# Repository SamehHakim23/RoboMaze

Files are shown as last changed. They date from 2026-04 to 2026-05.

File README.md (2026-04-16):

# RoboMaze — Autonomous Maze-Solving Robot

**ECNG 4504 — Embedded Systems for Wireless Communications**  
AUC Spring 2026 | Team 2

---

## Team Members

| Name | Student ID | Email |
|---|---|---|
| Sameh Ahmed | 900211681 | samehahmedhakim@aucegypt.edu |
| Hamza El Meadawy | 900211560 | hamzaelmeadwy@aucegypt.edu |
| Mariam Moataz | 900213249 | mariammoataz@aucegypt.edu |
| Menna AbdelHamed | 900212035 | mennnaa12@aucegypt.edu |

---

## Project Overview

RoboMaze is a fully autonomous maze-solving robot built on the ESP32 microcontroller. It uses a 5-sensor infrared array to follow black lines and navigate a maze autonomously across four sequential runs with no human intervention after the initial start command:

1. **LHR (Run 1)** — Explores the maze using the Left-Hand Rule, recording all junctions and decisions
2. **Back (Run 2)** — Returns to start along a simplified reverse path
3. **Run 2 (Run 3)** — Re-navigates the maze on the shortest discovered path using Manhattan distance heuristic
4. **Back 2 (Run 4)** — Returns to start along the optimized path

A live web application visualizes the maze map in real time and allows full wireless control via WiFi or Bluetooth BLE.

---

## Repository Structure

RoboMaze/
├── Firmware/           # ESP32 C++ source code (PlatformIO + Arduino)
├── Hardware(KiCad)/    # KiCad hardware schematic
├── Webapp/             # React + TypeScript web application
└── Docs/               # Architecture diagrams, contribution docs, team details

---

## Hardware

| Component | Model | Role |
|---|---|---|
| Microcontroller | ESP32 DevKit V1 | Main compute, WiFi 802.11, BLE 4.2 |
| IR Sensors | TCRT5000 × 5 | Line detection array |
| Motor Driver | L298N | Dual H-bridge PWM motor control |
| DC Motors | 25GA370 130RPM × 2 | Differential drive |
| Wheel Encoders | Hall-effect × 2 | Corridor distance measurement |

---

## Firmware

**Platform:** PlatformIO + Arduino Framework  
**Language:** C++  

Key features:
- Left-Hand Rule maze exploration with junction recording
- Triplet path simplification algorithm
- Run 2 Manhattan distance navigation with axis-priority selection
- WebSocket server on port 81 with full JSON telemetry protocol
- BLE GATT server with TX notify and RX write characteristics
- Encoder-based corridor distance measurement with auto-calibration

```ini
lib_deps =
    links2004/WebSockets@^2.4.0
    bblanchon/ArduinoJson@^6.21.0
board_build.partitions = huge_app.csv
```

---

## Web Application

**Stack:** React + TypeScript + Vite (frontend), Express (backend)  
**URL:** robomaze.net

Features:
- Live maze map with proportional corridor rendering
- Real-time sensor display and robot state indicator
- Full robot control panel (start, back, run2, back2, pause, e-stop)
- WiFi mode: direct browser → `ws://172.20.10.9:81`
- BLE mode: Web Bluetooth API (Chrome desktop)

---

## Wireless Communication

| Channel | Details |
|---|---|
| WiFi | Static IP 172.20.10.9 · WebSocket port 81 |
| BLE | Device: RoboMaze · Service UUID: 12345678-1234-1234-1234-123456789abc |
| Telnet | Port 23 · Raw log streaming |

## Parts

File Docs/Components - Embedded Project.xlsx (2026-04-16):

Hardware
Category | Component | Recommended Example | Purpose | Notes / Why Needed
MCU (Brain) | Microcontroller Board | ESP32 DevKit V1 | Runs all code, reads sensors, controls motors | Best choice because BLE is built-in for Phase 1
Sensors | IR Line Sensor Array | 5-channel QTR / IR array (TCRT5000) | Detects black line + intersections | 5 sensors makes intersection detection reliable
Motors | DC Gear Motors (x4) | 25ga370 | Movement of robot | Gear motors provide torque + stability
Motor Driver | Dual H-Bridge Driver | TB6612FNG | Drives motors with PWM + direction control | More efficient and modern than L298N
Chassis | Robot Car Frame | Acrylic / 4-wheel chassis | Holds all components | Must fit within 40×40 cm limit
Wheels | Robot Wheels (x4) | 65mm wheels | Movement traction | Match motor shaft type
Power
Category | Component | Recommended Example | Purpose | Notes
Battery | Li-ion / LiPo Battery Pack (x2) | 3.7v batteries | Powers motors + MCU | Strong enough for motors, stable voltage
Voltage Regulator | Buck Converter | LM2596 step-down | Converts battery → 5V/3.3V | ESP32 requires stable 5V input
Power Switch | Toggle switch | Any | On/off control | Required for safety
Wiring | Jumper wires + connectors | Male/Female Dupont | Connections during Phase 0 | Phase 2 replaces with PCB traces
Communication
Category | Component | Example | Purpose | Notes
USB Cable | USB-C / Micro USB | Depends on ESP32 board | Upload code + serial debugging | Required always
Optional BLE Module | Not needed | ESP32 has BLE built in | Wireless Phase 1 | Already included
Extra
Category | Component | Example | Purpose | Notes
Encoder (Optional Bonus) | Wheel encoder | Optical encoder | Measures speed accurately | Helps advanced PID + bonus sophistication
Breadboard (Temporary) | Mini breadboard | Any | Quick prototyping | Useful before soldering
Screws + Spacers | Mounting kit | M3 kit | Fix components on chassis | Makes build professional
3D Printed Parts | Custom mounts | PLA prints | Clean design | Bonus marks possible
Software
Software Category | Tool | Purpose | Why Needed | Notes
IDE / Coding | VS Code + PlatformIO | Write + upload ESP32 firmware | Best professional workflow for ESP32
Version Control | GitHub Repository | Required submission + teamwork | Doctor requires repo with MCU code + docs
Hardware Design | KiCAD | Wiring schematics + Phase 2 PCB | Hand drawing is not accepted
Serial Monitor | PlatformIO Serial Monitor | Debug sensor + motor values | Essential for tuning PID

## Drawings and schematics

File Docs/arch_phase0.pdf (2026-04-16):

# ROBOMAZE — SOFTWARE ARCH ITECTURE

## Phase 0 · Autonomous Maze Solver (LHR + Path Replay)

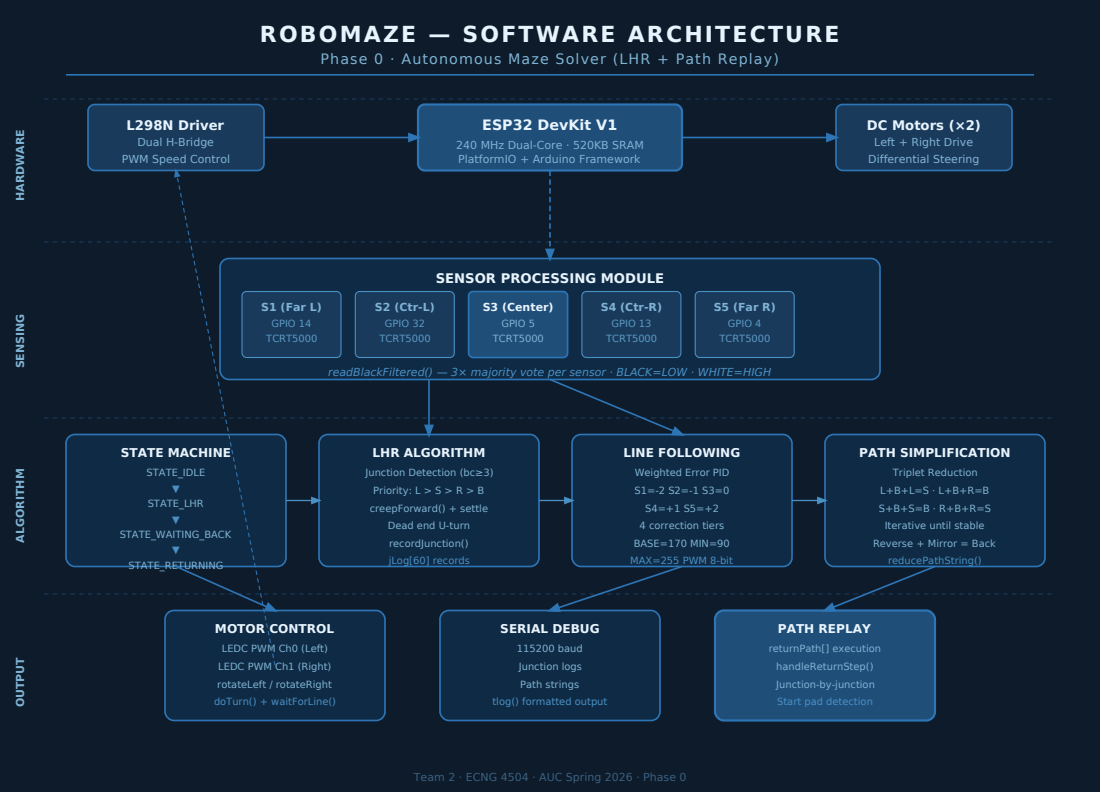
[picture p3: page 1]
S1 (Far L) GPIO 14 TCRT5000; S2 (Ctr-L) GPIO 32 TCRT5000; S3 (Center) GPIO 5 TCRT5000; S4 (Ctr-R) GPIO 13 TCRT5000; S5 (Far R) GPIO 4 TCRT5000; STATE MACHINE; STATE_IDLE ▼ STATE_LHR ▼ STATE_WAITING_BACK ▼ STATE_RETURNING

L298N Driver
Dual H-Bridge
PWM Speed Control

ESP32 DevKit V1
240 MHz Dual-Core · 520KB SRAM
PlatformIO + Arduino Framework

DC Motors (×2)
Left + Right Drive
Differential Steering

HARDWARE SENSING ALGORITHM OUTPUT

SENSOR PROCESSING MODULE

readBlackFiltered() — 3× majority vote per sensor · BLACK=LOW · WHITE=HIGH

LHR ALGORITHM
Junction Detection (bc≥3)
Priority: L > S > R > B
creepForward() + settle
Dead end U-turn
recordJunction()
jLog[60] records

LINE FOLLOWING
Weighted Error PID
4 correction tiers
BASE=170 MIN=90
MAX=255 PWM 8-bit

PATH SIMPLIFICATION
Triplet Reduction
Iterative until stable
Reverse + Mirror = Back
reducePathString()

MOTOR CONTROL
LEDC PWM Ch0 (Left)
LEDC PWM Ch1 (Right)
rotateLeft / rotateRight
doTurn() + waitForLine()

SERIAL DEBUG
115200 baud
Junction logs
Path strings
tlog() formatted output

PATH REPLAY
returnPath[] execution
handleReturnStep()
Junction-by-junction
Start pad detection

Team 2 · ECNG 4504 · AUC Spring 2026 · Phase 0

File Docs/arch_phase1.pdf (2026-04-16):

# ROBOMAZE — SOFTWARE ARCH ITECTURE

## Phase 1 · Full System with Wireless Communication

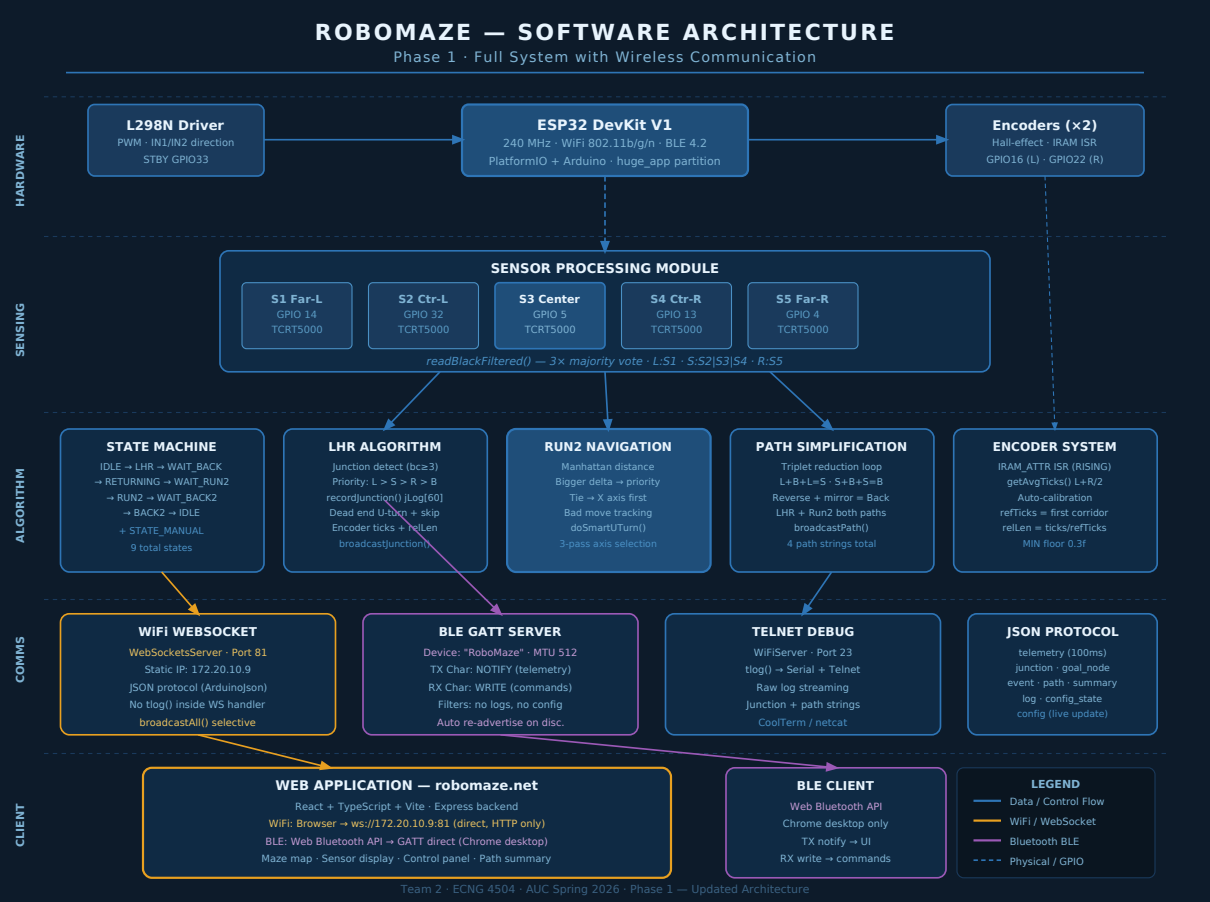
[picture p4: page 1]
L298N Driver; PWM · IN1/IN2 direction STBY GPIO33; S1 Far-L GPIO 14 TCRT5000; S2 Ctr-L GPIO 32 TCRT5000; S3 Center GPIO 5 TCRT5000; S4 Ctr-R GPIO 13 TCRT5000; S5 Far-R GPIO 4 TCRT5000; STATE MACHINE; IDLE → LHR → WAIT_BACK → RETURNING → WAIT_RUN2 → RUN2 → WAIT_BACK2 → BACK2 → IDLE; + STATE_MANUAL; 9 total states; LHR ALGORITHM; RUN2 NAVIGATION; PATH SIMPLIFICATION; ENCODER SYSTEM; JSON PROTOCOL

ESP32 DevKit V1
240 MHz · WiFi 802.11b/g/n · BLE 4.2
PlatformIO + Arduino · huge_app partition

Encoders (×2)
Hall-effect · IRAM ISR
GPIO16 (L) · GPIO22 (R)

HARDWARE SENSING ALGORITHM COMMS CLIENT

SENSOR PROCESSING MODULE

readBlackFiltered() — 3× majority vote · L:S1 · S:S2|S3|S4 · R:S5

Junction detect (bc≥3)
Priority: L > S > R > B
recordJunction() jLog[60]
Dead end U-turn + skip
Encoder ticks + relLen
broadcastJunction()

Manhattan distance
Bigger delta → priority
Tie → X axis first
Bad move tracking
doSmartUTurn()
3-pass axis selection

Triplet reduction loop
Reverse + mirror = Back
LHR + Run2 both paths
broadcastPath()
4 path strings total

IRAM_ATTR ISR (RISING)
getAvgTicks() L+R/2
Auto-calibration
refTicks = first corridor
relLen = ticks/refTicks
MIN floor 0.3f

WiFi WEBSOCKET
WebSocketsServer · Port 81
Static IP: 172.20.10.9
JSON protocol (ArduinoJson)
No tlog() inside WS handler
broadcastAll() selective

BLE GATT SERVER
Device: "RoboMaze" · MTU 512
TX Char: NOTIFY (telemetry)
RX Char: WRITE (commands)
Filters: no logs, no config
Auto re-advertise on disc.

TELNET DEBUG
WiFiServer · Port 23
tlog() → Serial + Telnet
Raw log streaming
Junction + path strings
CoolTerm / netcat

telemetry (100ms)
junction · goal_node
event · path · summary
log · config_state
config (live update)

WEB APPLICATION — robomaze.net

BLE CLIENT
Web Bluetooth API
Chrome desktop only
TX notify → UI
RX write → commands

LEGEND
Data / Control Flow
WiFi / WebSocket
Bluetooth BLE
Physical / GPIO

React + TypeScript + Vite · Express backend
WiFi: Browser → ws://172.20.10.9:81 (direct, HTTP only)
BLE: Web Bluetooth API → GATT direct (Chrome desktop)
Maze map · Sensor display · Control panel · Path summary

Team 2 · ECNG 4504 · AUC Spring 2026 · Phase 1 — Updated Architecture

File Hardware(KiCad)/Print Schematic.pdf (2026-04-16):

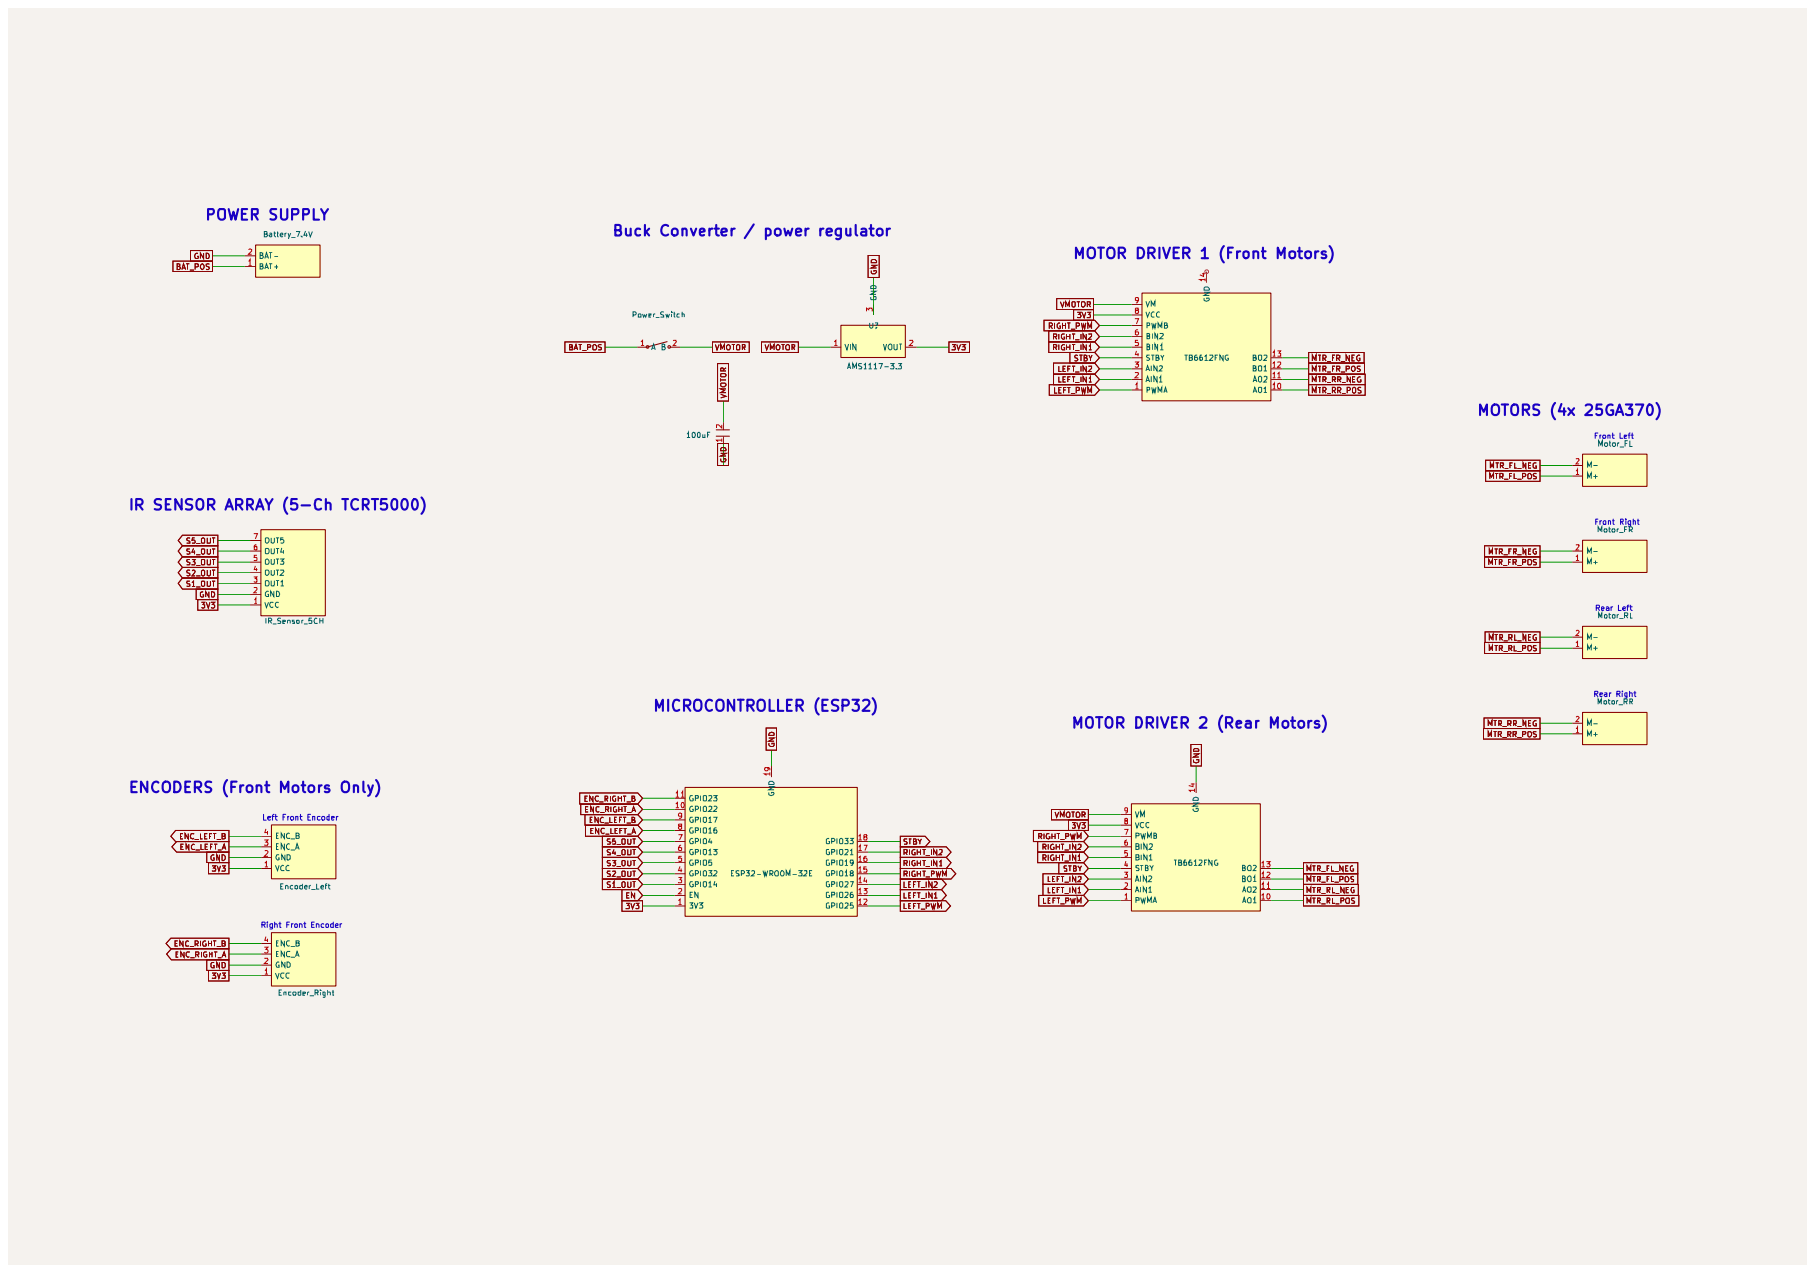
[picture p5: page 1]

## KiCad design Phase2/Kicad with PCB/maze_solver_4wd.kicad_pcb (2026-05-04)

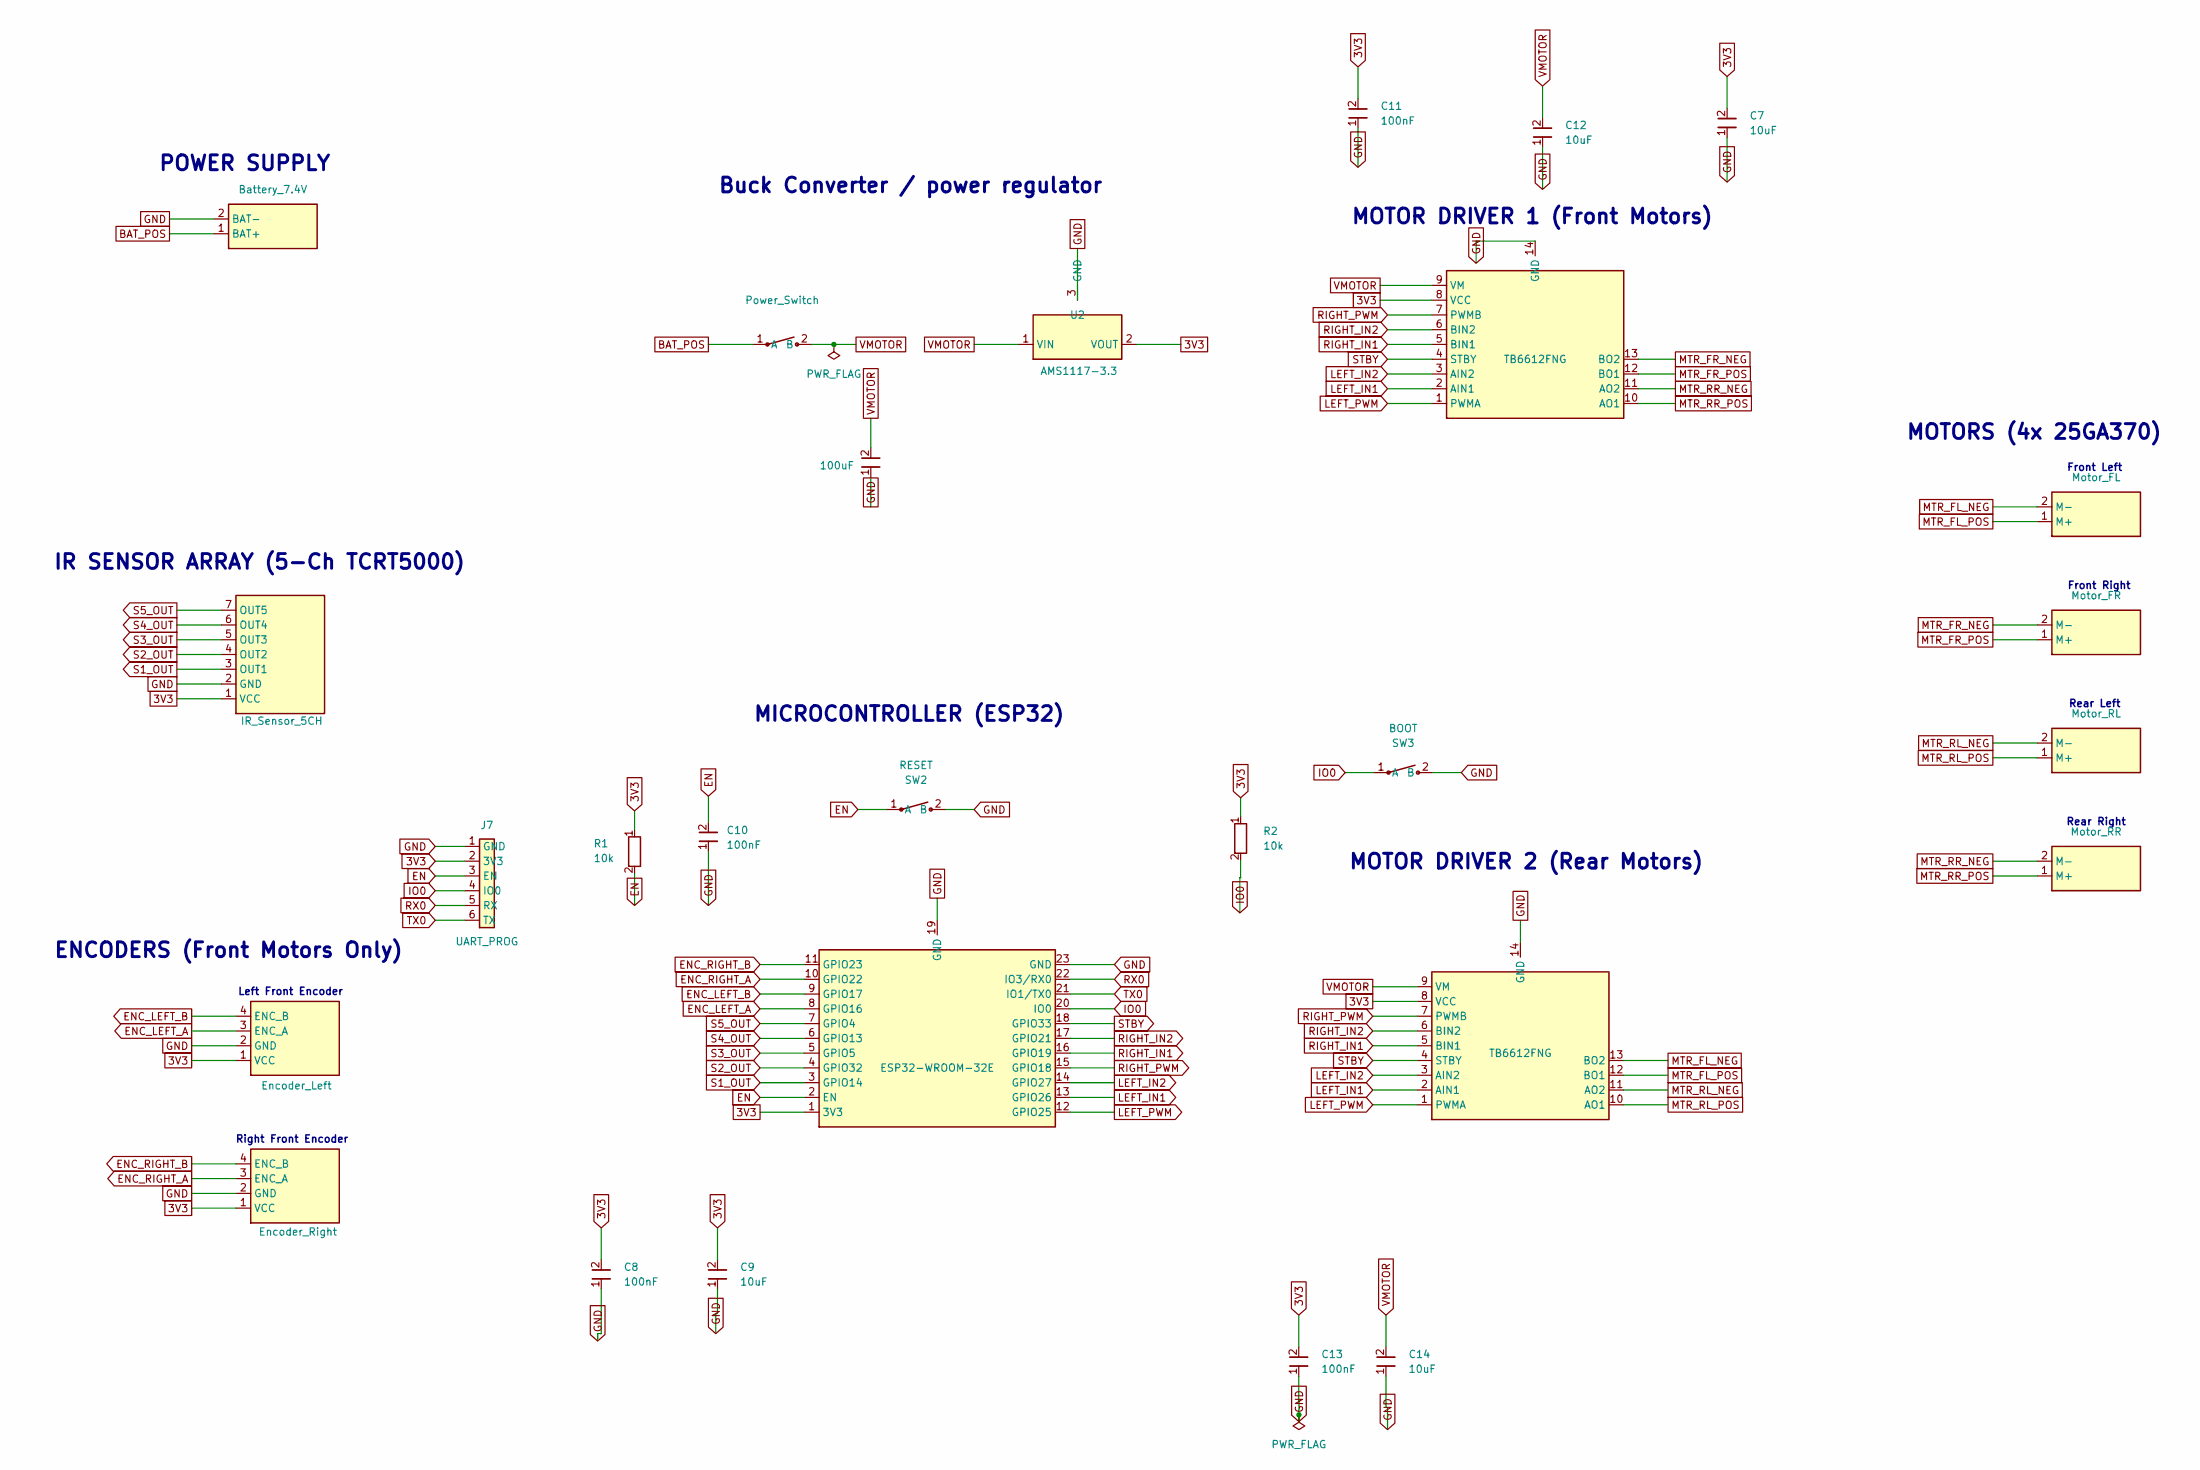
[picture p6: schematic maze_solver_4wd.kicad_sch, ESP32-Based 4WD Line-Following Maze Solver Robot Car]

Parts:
C1: 100uF; C_0805_2012Metric
C7, C9, C12, C14: 10uF; C_0805_2012Metric
C8, C10, C11, C13: 100nF; C_0805_2012Metric
J1: Battery_7.4V; JST_PH_S2B-PH-SM4-TB_1x02-1MP_P2.00mm_Horizontal
J2: IR_Sensor_5CH; PinHeader_1x07_P2.54mm_Vertical_SMD_Pin1Left
J3: Encoder_Left; JST_PH_S4B-PH-SM4-TB_1x04-1MP_P2.00mm_Horizontal
J4: Encoder_Right; JST_PH_S4B-PH-SM4-TB_1x04-1MP_P2.00mm_Horizontal
J5: Motor_FL; JST_PH_S2B-PH-SM4-TB_1x02-1MP_P2.00mm_Horizontal
J6: Motor_FR; JST_PH_S2B-PH-SM4-TB_1x02-1MP_P2.00mm_Horizontal
J7: UART_PROG; PinHeader_1x06_P2.54mm_Vertical_SMD_Pin1Left
J8: Motor_RL; JST_PH_S2B-PH-SM4-TB_1x02-1MP_P2.00mm_Horizontal
J9: Motor_RR; JST_PH_S2B-PH-SM4-TB_1x02-1MP_P2.00mm_Horizontal
R1, R2: 10k; R_0805_2012Metric
SW1: Power_Switch; SW_SPDT_PCM12
SW2: RESET; SW_SPST_TL3342
SW3: BOOT; SW_SPST_TL3342
U1: ESP32-WROOM-32E; ESP32-WROOM-32
U2: AMS1117-3.3; SOT-223-3_TabPin2
U3, U4: TB6612FNG; SSOP-24_5.3x8.2mm_P0.65mm

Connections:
3V3: C7.2, C8.2, C9.2, C11.2, C13.2, J2.1 (VCC), J3.1 (VCC), J4.1 (VCC), J7.2 (3V3), R1.1, R2.1, U1.1 (3V3), U2.2 (VOUT), U3.8 (VCC), U4.8 (VCC)
BAT_POS: J1.1 (BAT+), SW1.1 (A)
EN: C10.2, J7.3 (EN), R1.2, SW2.1 (A), U1.2 (EN)
ENC_LEFT_A: J3.3 (ENC_A), U1.8 (GPIO16)
ENC_LEFT_B: J3.4 (ENC_B), U1.9 (GPIO17)
ENC_RIGHT_A: J4.3 (ENC_A), U1.10 (GPIO22)
ENC_RIGHT_B: J4.4 (ENC_B), U1.11 (GPIO23)
GND: C1.1, C7.1, C8.1, C9.1, C10.1, C11.1, C12.1, C13.1, C14.1, J1.2 (BAT-), J2.2 (GND), J3.2 (GND), J4.2 (GND), J7.1 (GND), SW2.2 (B), SW3.2 (B), U1.19 (GND), U1.23 (GND), U2.3 (GND), U3.14 (GND), U4.14 (GND)
IO0: J7.4 (IO0), R2.2, SW3.1 (A), U1.20 (IO0)
LEFT_IN1: U1.13 (GPIO26), U3.2 (AIN1), U4.2 (AIN1)
LEFT_IN2: U1.14 (GPIO27), U3.3 (AIN2), U4.3 (AIN2)
LEFT_PWM: U1.12 (GPIO25), U3.1 (PWMA), U4.1 (PWMA)
MTR_FL_NEG: J5.2 (M-), U3.13 (BO2)
MTR_FL_POS: J5.1 (M+), U3.12 (BO1)
MTR_FR_NEG: J6.2 (M-), U4.13 (BO2)
MTR_FR_POS: J6.1 (M+), U4.12 (BO1)
MTR_RL_NEG: J8.2 (M-), U3.11 (AO2)
MTR_RL_POS: J8.1 (M+), U3.10 (AO1)
MTR_RR_NEG: J9.2 (M-), U4.11 (AO2)
MTR_RR_POS: J9.1 (M+), U4.10 (AO1)
RIGHT_IN1: U1.16 (GPIO19), U3.5 (BIN1), U4.5 (BIN1)
RIGHT_IN2: U1.17 (GPIO21), U3.6 (BIN2), U4.6 (BIN2)
RIGHT_PWM: U1.15 (GPIO18), U3.7 (PWMB), U4.7 (PWMB)
RX0: J7.5 (RX), U1.22 (IO3/RX0)
S1_OUT: J2.3 (OUT1), U1.3 (GPIO14)
S2_OUT: J2.4 (OUT2), U1.4 (GPIO32)
S3_OUT: J2.5 (OUT3), U1.5 (GPIO5)
S4_OUT: J2.6 (OUT4), U1.6 (GPIO13)
S5_OUT: J2.7 (OUT5), U1.7 (GPIO4)
STBY: U1.18 (GPIO33), U3.4 (STBY), U4.4 (STBY)
TX0: J7.6 (TX), U1.21 (IO1/TX0)
VMOTOR: C1.2, C12.2, C14.2, SW1.2 (B), U2.1 (VIN), U3.9 (VM), U4.9 (VM)

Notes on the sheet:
Front Left
Rear Right
Right Front Encoder
Left Front Encoder
Buck Converter / power regulator
MOTORS (4x 25GA370)
POWER SUPPLY
Rear Left
MOTOR DRIVER 1 (Front Motors)
IR SENSOR ARRAY (5-Ch TCRT5000)
MOTOR DRIVER 2 (Rear Motors)
MICROCONTROLLER (ESP32)
Front Right
ENCODERS (Front Motors Only)

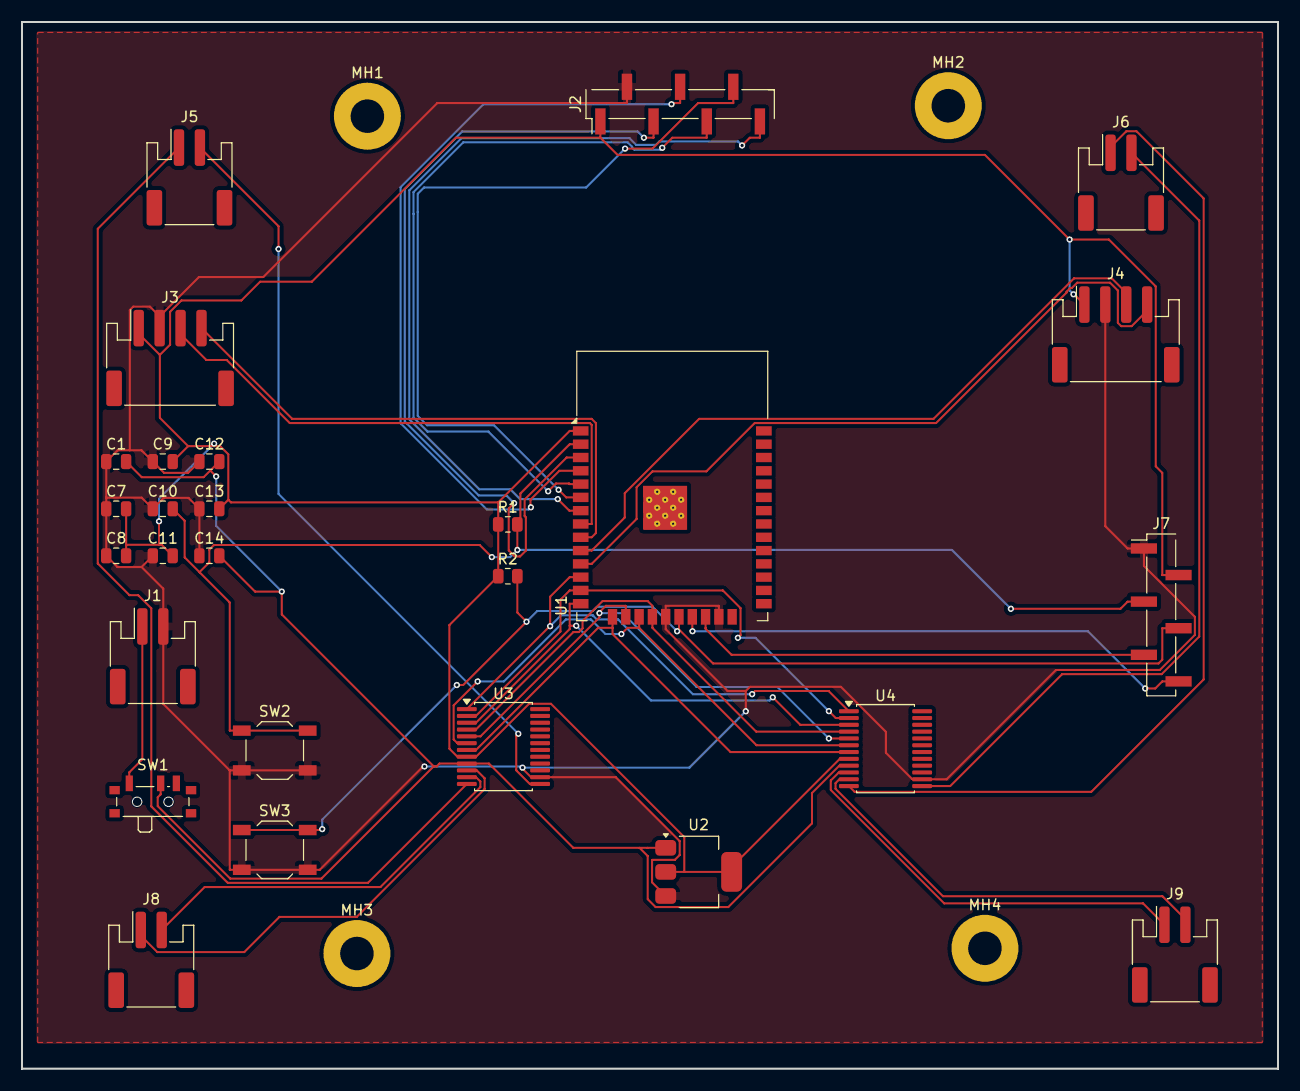
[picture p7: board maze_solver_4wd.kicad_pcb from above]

Board: 2 copper layers, 120.0 x 100.0 mm, 31 parts (0 on the bottom side), 32 nets.

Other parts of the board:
MH1, MH2, MH3, MH4: MountingHole_3.2mm_M3_Pad

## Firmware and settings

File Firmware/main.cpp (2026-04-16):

#include <Arduino.h>
#include <WiFi.h>
#include <WiFiServer.h>
#include <WebSocketsServer.h>
#include <ArduinoJson.h>
#include <BLEDevice.h>
#include <BLEServer.h>
#include <BLEUtils.h>
#include <BLE2902.h>

#define STBY_PIN  33
#define LEFT_PWM  25
#define LEFT_IN1  26
#define LEFT_IN2  27
#define RIGHT_PWM 18
#define RIGHT_IN1 19
#define RIGHT_IN2 21
#define S1 14
#define S2 32
#define S3 5
#define S4 13
#define S5 4

#define ENC_LEFT_A  16
#define ENC_RIGHT_A 22

#define PWM_FREQ 1000
#define PWM_RES  8
#define LEFT_CH  0
#define RIGHT_CH 1

#define BLE_SERVICE_UUID  "12345678-1234-1234-1234-123456789abc"
#define BLE_TX_CHAR_UUID  "12345678-1234-1234-1234-123456789abd"
#define BLE_RX_CHAR_UUID  "12345678-1234-1234-1234-123456789abe"
#define BLE_DEVICE_NAME   "RoboMaze"

const char* WIFI_SSID = "Samehs iphone";
const char* WIFI_PASS = "Sameh1234";
IPAddress staticIP(172, 20, 10, 9);
IPAddress gateway(172, 20, 10, 1);
IPAddress subnet(255, 255, 255, 240);
IPAddress dns(8, 8, 8, 8);

WiFiServer       telnetServer(23);
WiFiClient       telnetClient;
WebSocketsServer wsServer(81);

BLEServer*         pBLEServer      = nullptr;
BLECharacteristic* pTxChar         = nullptr;
BLECharacteristic* pRxChar         = nullptr;
bool               bleConnected    = false;
bool               bleWasConnected = false;
bool               wifiConnected   = false;

volatile long encLeftCount=0, encRightCount=0;
void IRAM_ATTR isrLeftA()  { encLeftCount++;  }
void IRAM_ATTR isrRightA() { encRightCount++; }
void resetEncoders() { encLeftCount=0; encRightCount=0; }
long getAvgTicks()   { return (encLeftCount+encRightCount)/2; }

long refTicks=0; bool refCalibrated=false;
void resetCalibration() { refTicks=0; refCalibrated=false; }
#define REL_LEN_MIN 0.3f
float computeRelLen(long ticks) {
  if(ticks<=0) return REL_LEN_MIN;
  if(!refCalibrated){ refTicks=ticks; refCalibrated=true; return 1.0f; }
  if(refTicks<=0) return REL_LEN_MIN;
  float r=(float)ticks/(float)refTicks;
  return r<REL_LEN_MIN?REL_LEN_MIN:r;
}

int BASE_SPEED=170, MIN_SPEED=90, MAX_SPEED=255, TURN_SPEED=130;
int CORR_TIER1=50, CORR_TIER2=55, CORR_TIER3=60, CORR_TIER4=65;
unsigned long SETTLE_TIME=300, JUNCTION_CREEP_TIME=275, GOAL_CREEP_TIME=150;
unsigned long SMART_UTURN_CREEP_TIME=25, PEEK_CREEP_TIME=150;
unsigned long FORCED_TURN_TIME=310, SEARCH_TIMEOUT=1700;
const unsigned long MANUAL_TURN_90=780, MANUAL_TURN_180=1560;
const unsigned long STOP_PAUSE=35, REACQUIRE_CONFIRM_MS=45;
const unsigned long LINE_LOST_TIMEOUT_MS=220, EVENT_LOCKOUT_MS=220;
const unsigned long TELEMETRY_INTERVAL_MS=100;

int  lastError=0;
unsigned long eventLockoutUntil=0, lastTelemetryMs=0;
int  currentPWML=0, currentPWMR=0;
bool gS1=false,gS2=false,gS3=false,gS4=false,gS5=false;
bool robotPaused=false;

enum RobotState {
  STATE_IDLE, STATE_LHR, STATE_WAITING_BACK,
  STATE_RETURNING, STATE_WAITING_RUN2, STATE_RUN2,
  STATE_WAITING_BACK2, STATE_BACK2, STATE_MANUAL
};
RobotState robotState=STATE_IDLE;

int currentHeading=0, currentX=0, currentY=0;
const int dX[4]={0,1,0,-1}, dY[4]={1,0,-1,0};
#define MAX_JUNCTIONS 60

struct JunctionRecord {
  int id,x,y,headingOnArrival;
  bool hasL,hasS,hasR; char decision; long ticks; float relLen;
};
JunctionRecord jLog[MAX_JUNCTIONS];
int jCount=0, goalX=0, goalY=0;

char returnPath[MAX_JUNCTIONS*2+1]; int returnPathLen=0, returnPathIdx=0;
char run2Decisions[MAX_JUNCTIONS];  int run2Count=0;
char back2Path[MAX_JUNCTIONS*2+1];  int back2PathLen=0, back2PathIdx=0;

String lhrSimplifiedStr="", run2SimplifiedStr="", wsCommandBuffer="";

void tlog(const char* fmt, ...);
const char* hName(int h); const char* hShort(int h);
void stopMotors(); void broadcastTelemetry();
void broadcastAll(String msg); void broadcastEvent(const char* et, const char* msg);

#define MAX_BAD 60
struct BadMove { int x,y,absDir; };
BadMove run2Bad[MAX_BAD];
int run2BadCount=0, run2LastJX=0, run2LastJY=0, run2LastAbsDir=0;
bool run2JustBacktracked=false;

void resetRun2Backtracking() {
  run2BadCount=0; run2LastJX=run2LastJY=run2LastAbsDir=0;
  run2JustBacktracked=false;
}
bool isMoveBad(int x,int y,int absDir) {
  for(int i=0;i<run2BadCount;i++)
    if(run2Bad[i].x==x&&run2Bad[i].y==y&&run2Bad[i].absDir==absDir) return true;
  return false;
}
void markLastMoveBad() {
  if(run2BadCount>=MAX_BAD) return;
  if(isMoveBad(run2LastJX,run2LastJY,run2LastAbsDir)) return;
  run2Bad[run2BadCount++]={run2LastJX,run2LastJY,run2LastAbsDir};
  tlog("[BAD] (%d,%d) dir=%s\n",run2LastJX,run2LastJY,hShort(run2LastAbsDir));
}

class RoboServerCallbacks : public BLEServerCallbacks {
  void onConnect(BLEServer*)    override { bleConnected=true; }
  void onDisconnect(BLEServer*) override { bleConnected=false; bleWasConnected=true; }
};

void applyConfig(StaticJsonDocument<256>& doc) {
  if(doc.containsKey("baseSpeed"))     BASE_SPEED         =doc["baseSpeed"];
  if(doc.containsKey("turnSpeed"))     TURN_SPEED         =doc["turnSpeed"];
  if(doc.containsKey("minSpeed"))      MIN_SPEED          =doc["minSpeed"];
  if(doc.containsKey("settleTime"))    SETTLE_TIME        =doc["settleTime"];
  if(doc.containsKey("junctionCreep")) JUNCTION_CREEP_TIME=doc["junctionCreep"];
  if(doc.containsKey("forcedTurn"))    FORCED_TURN_TIME   =doc["forcedTurn"];
  if(doc.containsKey("searchTimeout")) SEARCH_TIMEOUT     =doc["searchTimeout"];
  if(doc.containsKey("corrT1"))        CORR_TIER1         =doc["corrT1"];
  if(doc.containsKey("corrT2"))        CORR_TIER2         =doc["corrT2"];
  if(doc.containsKey("corrT3"))        CORR_TIER3         =doc["corrT3"];
  if(doc.containsKey("corrT4"))        CORR_TIER4         =doc["corrT4"];
  tlog("[CONFIG] BASE=%d TURN=%d\n",BASE_SPEED,TURN_SPEED);
  broadcastEvent("CONFIG_UPDATED","Parameters updated");
}

class BLERxCallbacks : public BLECharacteristicCallbacks {
  void onWrite(BLECharacteristic* pChar) override {
    String val=pChar->getValue().c_str(); val.trim();
    if(!val.length()) return;
    StaticJsonDocument<256> doc;
    if(deserializeJson(doc,val)==DeserializationError::Ok) {
      const char* cmd=doc["cmd"];
      if(cmd){
        if(String(cmd)=="config"){ applyConfig(doc); return; }
        wsCommandBuffer=String(cmd); wsCommandBuffer.trim(); wsCommandBuffer.toLowerCase();
      }
    }
  }
};

// ==================================================
// BROADCAST
// WiFi: everything
// BLE:  everything EXCEPT logs and config_state
//       logs = noise, config_state = too large
//       telemetry passes through so sensors work
// ==================================================
void broadcastAll(String msg) {
  if(wifiConnected) wsServer.broadcastTXT(msg);
  if(bleConnected && pTxChar) {
    bool isLog        = msg.indexOf("\"type\":\"log\"")==-1         ? false : true;
    bool isConfigState= msg.indexOf("\"type\":\"config_state\"")==-1 ? false : true;
    if(!isLog && !isConfigState && msg.length()<=500){
      pTxChar->setValue(msg.c_str());
      pTxChar->notify();
      delay(20);
    }
  }
}

void bleNotify(String msg) {
  if(!bleConnected || !pTxChar) return;
  if(msg.length()>500) msg=msg.substring(0,497)+"...";
  pTxChar->setValue(msg.c_str());
  pTxChar->notify();
  delay(30);
}

void onWebSocketEvent(uint8_t clientNum,WStype_t type,uint8_t* payload,size_t length) {
  if(type==WStype_CONNECTED) {
    Serial.printf("[WS] Client #%d connected\n",clientNum);
    wsServer.sendTXT(clientNum,"{\"type\":\"connected\",\"version\":\"3.0\"}");
    StaticJsonDocument<256> cfg;
    cfg["type"]="config_state"; cfg["baseSpeed"]=BASE_SPEED; cfg["turnSpeed"]=TURN_SPEED;
    cfg["minSpeed"]=MIN_SPEED; cfg["settleTime"]=SETTLE_TIME;
    cfg["junctionCreep"]=JUNCTION_CREEP_TIME; cfg["forcedTurn"]=FORCED_TURN_TIME;
    cfg["searchTimeout"]=SEARCH_TIMEOUT; cfg["corrT1"]=CORR_TIER1;
    cfg["corrT2"]=CORR_TIER2; cfg["corrT3"]=CORR_TIER3; cfg["corrT4"]=CORR_TIER4;
    String cfgOut; serializeJson(cfg,cfgOut); wsServer.sendTXT(clientNum,cfgOut);
  }
  else if(type==WStype_DISCONNECTED) {
    Serial.printf("[WS] Client #%d disconnected\n",clientNum);
  }
  else if(type==WStype_TEXT) {
    StaticJsonDocument<256> doc;
    if(deserializeJson(doc,payload,length)!=DeserializationError::Ok) return;
    const char* cmd=doc["cmd"];
    if(!cmd) return;
    Serial.printf("[WS] Cmd: %s\n",cmd);
    if(String(cmd)=="config"){ applyConfig(doc); return; }
    wsCommandBuffer=String(cmd); wsCommandBuffer.trim(); wsCommandBuffer.toLowerCase();
  }
}

const char* stateStr() {
  switch(robotState){
    case STATE_IDLE:          return "IDLE";
    case STATE_LHR:           return "LHR";
    case STATE_WAITING_BACK:  return "WAITING_BACK";
    case STATE_RETURNING:     return "RETURNING";
    case STATE_WAITING_RUN2:  return "WAITING_RUN2";
    case STATE_RUN2:          return "RUN2";
    case STATE_WAITING_BACK2: return "WAITING_BACK2";
    case STATE_BACK2:         return "BACK2";
    case STATE_MANUAL:        return "MANUAL";
    default:                  return "UNKNOWN";
  }
}

// Telemetry at 100ms — passes through BLE so sensors display works
void broadcastTelemetry() {
  if(millis()-lastTelemetryMs<TELEMETRY_INTERVAL_MS) return;
  lastTelemetryMs=millis();
  StaticJsonDocument<256> doc;
  doc["type"]="telemetry"; doc["state"]=stateStr(); doc["paused"]=robotPaused;
  doc["x"]=currentX; doc["y"]=currentY; doc["heading"]=hShort(currentHeading);
  doc["pwmL"]=currentPWML; doc["pwmR"]=currentPWMR;
  doc["goalX"]=goalX; doc["goalY"]=goalY;
  JsonArray s=doc.createNestedArray("sensors");
  s.add(gS1?1:0);s.add(gS2?1:0);s.add(gS3?1:0);s.add(gS4?1:0);s.add(gS5?1:0);
  String out; serializeJson(doc,out); broadcastAll(out);
}

void broadcastEvent(const char* et,const char* msg) {
  StaticJsonDocument<200> doc;
  doc["type"]="event"; doc["event"]=et; doc["message"]=msg;
  doc["x"]=currentX; doc["y"]=currentY; doc["heading"]=hShort(currentHeading);
  String out; serializeJson(doc,out); broadcastAll(out);
}

void broadcastJunction(bool hasL,bool hasS,bool hasR,char decision,long ticks,float relLen) {
  StaticJsonDocument<192> doc;
  doc["type"]="junction"; doc["id"]=jCount;
  doc["x"]=currentX; doc["y"]=currentY; doc["heading"]=hShort(currentHeading);
  doc["hasL"]=hasL; doc["hasS"]=hasS; doc["hasR"]=hasR;
  doc["decision"]=String(decision); doc["ticks"]=ticks;
  doc["relLen"]=(float)((int)(relLen*100+0.5f))/100.0f;
  String out; serializeJson(doc,out); broadcastAll(out);
}

void broadcastGoalNode() {
  StaticJsonDocument<100> doc;
  doc["type"]="goal_node"; doc["x"]=goalX; doc["y"]=goalY;
  doc["heading"]=hShort(currentHeading);
  String out; serializeJson(doc,out); broadcastAll(out);
}

void broadcastPath(const char* pathType,const char* pathStr) {
  StaticJsonDocument<256> doc;
  doc["type"]="path"; doc["path"]=pathType; doc["data"]=pathStr;
  String out; serializeJson(doc,out); broadcastAll(out);
}

void handleTelnet() {
  if(!wifiConnected) return;
  if(!telnetClient||!telnetClient.connected()){
    telnetClient=telnetServer.available();
    if(telnetClient){ Serial.println("[TELNET] Connected"); telnetClient.println("=== MAZE ROBOT v3.0 ==="); }
  }
}

// tlog goes to Serial + Telnet + WiFi only — never BLE (noise)
void tlog(const char* fmt,...) {
  char buf[256];
  va_list a; va_start(a,fmt); vsnprintf(buf,sizeof(buf),fmt,a); va_end(a);
  Serial.print(buf);
  if(wifiConnected&&telnetClient&&telnetClient.connected()) telnetClient.print(buf);
  if(wifiConnected){
    StaticJsonDocument<300> doc;
    doc["type"]="log"; doc["msg"]=buf;
    String out; serializeJson(doc,out); wsServer.broadcastTXT(out);
  }
}

void sep()    { tlog("---\n"); }
void bigSep() { tlog("===================================\n"); }

const char* hName(int h) { const char* n[]={"N(+Y)","E(+X)","S(-Y)","W(-X)"}; return (h>=0&&h<4)?n[h]:"?"; }
const char* hShort(int h){ const char* n[]={"N","E","S","W"}; return (h>=0&&h<4)?n[h]:"?"; }
void updateHeading(char dir) {
  if(dir=='L') currentHeading=(currentHeading+3)%4;
  else if(dir=='R') currentHeading=(currentHeading+1)%4;
  else if(dir=='B') currentHeading=(currentHeading+2)%4;
}

void recordJunction(bool hasL,bool hasS,bool hasR,char dec,long corridorTicks=0) {
  float relLen=computeRelLen(corridorTicks);
  currentX+=dX[currentHeading]; currentY+=dY[currentHeading];
  if(jCount<MAX_JUNCTIONS){
    jLog[jCount]={jCount,currentX,currentY,currentHeading,hasL,hasS,hasR,dec,corridorTicks,relLen};
    jCount++;
  }
  broadcastJunction(hasL,hasS,hasR,dec,corridorTicks,relLen);
  tlog("[JCT #%02d] (%d,%d) %s L=%d S=%d R=%d ->%c ticks=%ld rel=%.2f\n",
       jCount-1,currentX,currentY,hName(currentHeading),hasL,hasS,hasR,dec,corridorTicks,relLen);
}

void printLHRMap() {
  tlog("\n"); bigSep(); tlog("  LHR MAP\n"); bigSep();
  for(int i=0;i<jCount;i++){
    JunctionRecord& j=jLog[i];
    tlog("  J%02d (%d,%d) %s [L=%d S=%d R=%d] ->%c ticks=%ld rel=%.2f\n",
         j.id,j.x,j.y,hShort(j.headingOnArrival),j.hasL,j.hasS,j.hasR,j.decision,j.ticks,j.relLen);
  }
  bigSep();
  String raw=""; for(int i=0;i<jCount;i++) raw+=jLog[i].decision;
  broadcastPath("lhr_raw",raw.c_str());
  broadcastEvent("GOAL_REACHED","LHR complete");
}

void printRun2Map() {
  tlog("\n"); bigSep(); tlog("  RUN2 RESULT\n"); bigSep();
  tlog("  Goal: (%d,%d)  Arrived: (%d,%d)\n",goalX,goalY,currentX,currentY);
  String r=""; for(int i=0;i<run2Count;i++) r+=run2Decisions[i];
  tlog("  Run2: %s\n",r.c_str()); bigSep();
  broadcastPath("run2_raw",r.c_str());
  broadcastEvent("RUN2_GOAL","Run2 complete");
}

void printFullSummary() {
  String lhrRaw=""; for(int i=0;i<jCount;i++) lhrRaw+=jLog[i].decision;
  String run2Raw=""; for(int i=0;i<run2Count;i++) run2Raw+=run2Decisions[i];
  String back2Str=""; for(int i=0;i<back2PathLen;i++) back2Str+=back2Path[i];
  String backStr=""; for(int i=0;i<returnPathLen;i++) backStr+=returnPath[i];
  tlog("\n"); bigSep(); tlog("  FULL SUMMARY\n"); bigSep();
  tlog("  1. LHR   (%d): %s\n",lhrRaw.length(),lhrRaw.c_str());
  tlog("     Simp  (%d): %s\n",lhrSimplifiedStr.length(),lhrSimplifiedStr.c_str());
  tlog("  2. Back  (%d): %s\n",backStr.length(),backStr.c_str());
  tlog("  3. Run2  (%d): %s\n",run2Raw.length(),run2Raw.c_str());
  tlog("     Simp  (%d): %s\n",run2SimplifiedStr.length(),run2SimplifiedStr.c_str());
  tlog("  4. Back2 (%d): %s\n",back2Str.length(),back2Str.c_str());
  bigSep();

  // WiFi: full summary JSON
  if(wifiConnected){
    StaticJsonDocument<512> doc;
    doc["type"]="summary"; doc["goalX"]=goalX; doc["goalY"]=goalY;
    doc["lhr_raw"]=lhrRaw; doc["lhr_simplified"]=lhrSimplifiedStr; doc["back"]=backStr;
    doc["run2_raw"]=run2Raw; doc["run2_simplified"]=run2SimplifiedStr; doc["back2"]=back2Str;
    String out; serializeJson(doc,out); wsServer.broadcastTXT(out);
  }

  // BLE: individual path strings — short and clean
  if(bleConnected && pTxChar){
    bleNotify("{\"type\":\"ble_summary\",\"goalX\":"+String(goalX)+",\"goalY\":"+String(goalY)+"}");
    bleNotify("{\"type\":\"path\",\"path\":\"lhr_raw\",\"data\":\""+lhrRaw+"\"}");
    bleNotify("{\"type\":\"path\",\"path\":\"lhr_simplified\",\"data\":\""+lhrSimplifiedStr+"\"}");
    bleNotify("{\"type\":\"path\",\"path\":\"back\",\"data\":\""+backStr+"\"}");
    bleNotify("{\"type\":\"path\",\"path\":\"run2_raw\",\"data\":\""+run2Raw+"\"}");
    bleNotify("{\"type\":\"path\",\"path\":\"run2_simplified\",\"data\":\""+run2SimplifiedStr+"\"}");
    bleNotify("{\"type\":\"path\",\"path\":\"back2\",\"data\":\""+back2Str+"\"}");
  }
}

void leftForward()   {digitalWrite(LEFT_IN1,LOW); digitalWrite(LEFT_IN2,HIGH);}
void leftBackward()  {digitalWrite(LEFT_IN1,HIGH);digitalWrite(LEFT_IN2,LOW); }
void rightForward()  {digitalWrite(RIGHT_IN1,HIGH);digitalWrite(RIGHT_IN2,LOW);}
void rightBackward() {digitalWrite(RIGHT_IN1,LOW);digitalWrite(RIGHT_IN2,HIGH);}
void bothForward()  {leftForward();  rightForward();}
void bothBackward() {leftBackward(); rightBackward();}
void rotateLeft()   {leftBackward(); rightForward();}
void rotateRight()  {leftForward();  rightBackward();}

void stopMotors() {
  ledcWrite(LEFT_CH,0); ledcWrite(RIGHT_CH,0); currentPWML=0; currentPWMR=0;
}
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
void loop() {
  handleTelnet();
  if(wifiConnected) wsServer.loop();
  updateSensorGlobals(); broadcastTelemetry(); checkCommands();
  if(bleWasConnected&&!bleConnected){ bleWasConnected=false; BLEDevice::startAdvertising(); tlog("[BLE] Adv restarted\n"); }
  if(robotPaused) return;
  if(robotState==STATE_IDLE||robotState==STATE_MANUAL||
     robotState==STATE_WAITING_BACK||robotState==STATE_WAITING_RUN2||
     robotState==STATE_WAITING_BACK2) return;

  bool s1,s2,s3,s4,s5; readSensors(s1,s2,s3,s4,s5);
  int bc=countBlack(s1,s2,s3,s4,s5);
  if(millis()<eventLockoutUntil){ lineFollowStep(s1,s2,s3,s4,s5); return; }

  if(bc>=3){
    stopMotors(); delayWS(SETTLE_TIME);
    bool rs1,rs2,rs3,rs4,rs5; readSensors(rs1,rs2,rs3,rs4,rs5);
    int rbc=countBlack(rs1,rs2,rs3,rs4,rs5);
    tlog("\n"); sep(); tlog("[STOP] %s count=%d state=%s\n",pat(rs1,rs2,rs3,rs4,rs5).c_str(),rbc,stateStr());
    bool settledL=rs1, settledR=rs5, alreadyCreped=false;

    if(rbc>=4){
      tlog("[GOAL/START?]\n");
      bothForward(); setPWM(BASE_SPEED,BASE_SPEED); delayWS(GOAL_CREEP_TIME); stopMotors(); delay(STOP_PAUSE);
      bool gs1,gs2,gs3,gs4,gs5; readSensors(gs1,gs2,gs3,gs4,gs5);
      int gbc=countBlack(gs1,gs2,gs3,gs4,gs5);
      tlog("[CHECK] %s count=%d\n",pat(gs1,gs2,gs3,gs4,gs5).c_str(),gbc);
      if(gbc>=4){
        stopMotors();
        if(robotState==STATE_LHR){
          goalX=currentX+dX[currentHeading]; goalY=currentY+dY[currentHeading];
          broadcastGoalNode(); printLHRMap(); tlog("  GOAL at (%d,%d)\n",goalX,goalY);
          robotState=STATE_WAITING_BACK; broadcastEvent("WAITING_BACK","Goal — send back"); return;
        }
        else if(robotState==STATE_RETURNING){
          tlog("  START REACHED\n");
          bothBackward(); setPWM(BASE_SPEED,BASE_SPEED); delayWS(JUNCTION_CREEP_TIME); stopMotors(); delayWS(200);
          doTurn('B'); waitForLine(SEARCH_TIMEOUT); stopMotors(); delay(STOP_PAUSE);
          currentX=0; currentY=0; currentHeading=0;
          robotState=STATE_WAITING_RUN2; broadcastEvent("WAITING_RUN2","At start — send run2"); return;
        }
        else if(robotState==STATE_RUN2){
          currentX+=dX[currentHeading]; currentY+=dY[currentHeading]; printRun2Map();
          tlog("  RUN2 GOAL at (%d,%d)\n",currentX,currentY);
          robotState=STATE_WAITING_BACK2; broadcastEvent("WAITING_BACK2","Run2 goal — send back2"); return;
        }
        else if(robotState==STATE_BACK2){
          tlog("  ALL COMPLETE\n");
          bothBackward(); setPWM(BASE_SPEED,BASE_SPEED); delayWS(JUNCTION_CREEP_TIME); stopMotors(); delayWS(200);
          doTurn('B'); waitForLine(SEARCH_TIMEOUT); stopMotors(); delay(STOP_PAUSE);
          printFullSummary(); robotState=STATE_IDLE; broadcastEvent("COMPLETE","All done"); return;
        }
      }
      unsigned long topUp=(JUNCTION_CREEP_TIME>GOAL_CREEP_TIME)?(JUNCTION_CREEP_TIME-GOAL_CREEP_TIME):0;
      if(topUp>0){ bothForward(); setPWM(BASE_SPEED,BASE_SPEED); delayWS(topUp); stopMotors(); delay(STOP_PAUSE); }
      alreadyCreped=true;
      readSensors(gs1,gs2,gs3,gs4,gs5);
      settledL=settledL||gs1; settledR=settledR||gs5;
      tlog("[JCT] L=%d R=%d\n",settledL,settledR);
    }

    tlog("[JCT TYPE] L=%d R=%d C=%d\n",settledL,settledR,rs3);

    if(robotState==STATE_LHR){
      if(!settledL&&!settledR){
        if(rs2||rs3||rs4){ tlog("[UNCLEAR]\n"); handleJunctionLHR(false,false,alreadyCreped); }
        else{ tlog("[DEAD END]\n"); long ct=getAvgTicks(); recordJunction(false,false,false,'B',ct); resetEncoders(); doTurn('B'); startEventLockout(); }
      } else handleJunctionLHR(settledL,settledR,alreadyCreped);
    }
    else if(robotState==STATE_RETURNING) handleReturnStep(alreadyCreped);
    else if(robotState==STATE_RUN2){
      if(!settledL&&!settledR){
        if(rs2||rs3||rs4){ tlog("[UNCLEAR]\n"); handleJunctionRun2(false,false,alreadyCreped); }
        else{ tlog("[RUN2 DEAD END]\n"); markLastMoveBad(); run2JustBacktracked=true; doTurn('B'); startEventLockout(); }
      } else handleJunctionRun2(settledL,settledR,alreadyCreped);
    }
    else if(robotState==STATE_BACK2) handleBack2Step(alreadyCreped);
    return;
  }

  static bool deadActive=false; static unsigned long deadStart=0;
  bool anyLine=s1||s2||s3||s4||s5;
  if(!anyLine){
    if(!deadActive){deadActive=true;deadStart=millis();}
    if(millis()-deadStart>=LINE_LOST_TIMEOUT_MS){
      stopMotors(); delay(STOP_PAUSE); deadActive=false; tlog("\n[LINE LOST]\n");
      resetEncoders(); bothForward(); setPWM(BASE_SPEED,BASE_SPEED); delayWS(PEEK_CREEP_TIME); stopMotors(); delay(STOP_PAUSE);
      bool pk1,pk2,pk3,pk4,pk5; readSensors(pk1,pk2,pk3,pk4,pk5);
      int pkc=countBlack(pk1,pk2,pk3,pk4,pk5);
      tlog("[PEEK] %s %d\n",pat(pk1,pk2,pk3,pk4,pk5).c_str(),pkc);
      bool pL=pk1, pR=pk5;
      if(pkc>=3){
        if(robotState==STATE_LHR){ if(pL||pR) handleJunctionLHR(pL,pR); else{ long ct=getAvgTicks(); recordJunction(false,false,false,'B',ct); resetEncoders(); doTurn('B'); startEventLockout(); } }
        else if(robotState==STATE_RETURNING) handleReturnStep();
        else if(robotState==STATE_RUN2){ if(pL||pR) handleJunctionRun2(pL,pR); else{ tlog("[RUN2 DEAD END]\n"); markLastMoveBad(); run2JustBacktracked=true; doTurn('B'); startEventLockout(); } }
        else if(robotState==STATE_BACK2) handleBack2Step();
      } else {
        if(robotState==STATE_LHR){ tlog("[DEAD END]\n"); long ct=getAvgTicks(); recordJunction(false,false,false,'B',ct); resetEncoders(); doTurn('B'); startEventLockout(); }
        else if(robotState==STATE_RETURNING) handleReturnStep();
        else if(robotState==STATE_RUN2){ tlog("[RUN2 DEAD END]\n"); markLastMoveBad(); run2JustBacktracked=true; doTurn('B'); startEventLockout(); }
        else if(robotState==STATE_BACK2) handleBack2Step();
      }
    }
    return;
  } else { deadActive=false; }

  lineFollowStep(s1,s2,s3,s4,s5);
}

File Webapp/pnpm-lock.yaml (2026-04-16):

lockfileVersion: '9.0'

settings:
  autoInstallPeers: false
  excludeLinksFromLockfile: false

catalogs:
  default:
    '@replit/vite-plugin-cartographer':
      specifier: ^0.5.0
      version: 0.5.0
    '@replit/vite-plugin-dev-banner':
      specifier: ^0.1.1
      version: 0.1.2
    '@replit/vite-plugin-runtime-error-modal':
      specifier: ^0.0.6
      version: 0.0.6
    '@tailwindcss/vite':
      specifier: ^4.1.14
      version: 4.2.1
    '@tanstack/react-query':
      specifier: ^5.90.21
      version: 5.90.21
    '@types/node':
      specifier: ^25.3.3
      version: 25.3.5
    '@types/react':
      specifier: ^19.2.0
      version: 19.2.14
    '@types/react-dom':
      specifier: ^19.2.0
      version: 19.2.3
    '@vitejs/plugin-react':
      specifier: ^5.0.4
      version: 5.1.4
    class-variance-authority:
      specifier: ^0.7.1
      version: 0.7.1
    clsx:
      specifier: ^2.1.1
      version: 2.1.1
    drizzle-orm:
      specifier: ^0.45.1
      version: 0.45.1
    framer-motion:
      specifier: 12.35.1
      version: 12.35.1
    lucide-react:
      specifier: ^0.545.0
      version: 0.545.0
    react:
      specifier: 19.1.0
      version: 19.1.0
    react-dom:
      specifier: 19.1.0
      version: 19.1.0
    tailwind-merge:
      specifier: ^3.3.1
      version: 3.5.0
    tailwindcss:
      specifier: ^4.1.14
      version: 4.2.1
    tsx:
      specifier: ^4.21.0
      version: 4.21.0
    vite:
      specifier: ^7.3.0
      version: 7.3.1
    zod:
      specifier: ^3.25.76
      version: 3.25.76

overrides:
  esbuild>@esbuild/darwin-arm64: '-'
  esbuild>@esbuild/darwin-x64: '-'
  esbuild>@esbuild/freebsd-arm64: '-'
  esbuild>@esbuild/freebsd-x64: '-'
  esbuild>@esbuild/linux-arm: '-'
  esbuild>@esbuild/linux-arm64: '-'
  esbuild>@esbuild/linux-ia32: '-'
  esbuild>@esbuild/linux-loong64: '-'
  esbuild>@esbuild/linux-mips64el: '-'
  esbuild>@esbuild/linux-ppc64: '-'
  esbuild>@esbuild/linux-riscv64: '-'
  esbuild>@esbuild/linux-s390x: '-'
  esbuild>@esbuild/netbsd-arm64: '-'
  esbuild>@esbuild/netbsd-x64: '-'
  esbuild>@esbuild/openbsd-arm64: '-'
  esbuild>@esbuild/openbsd-x64: '-'
  esbuild>@esbuild/sunos-x64: '-'
  esbuild>@esbuild/win32-arm64: '-'
  esbuild>@esbuild/win32-ia32: '-'
  esbuild>@esbuild/win32-x64: '-'
  esbuild>@esbuild/aix-ppc64: '-'
  esbuild>@esbuild/android-arm: '-'
  esbuild>@esbuild/android-arm64: '-'
  esbuild>@esbuild/android-x64: '-'
  esbuild>@esbuild/openharmony-arm64: '-'
  lightningcss>lightningcss-android-arm64: '-'
  lightningcss>lightningcss-darwin-arm64: '-'
  lightningcss>lightningcss-darwin-x64: '-'
  lightningcss>lightningcss-freebsd-x64: '-'
  lightningcss>lightningcss-linux-arm-gnueabihf: '-'
  lightningcss>lightningcss-linux-arm64-gnu: '-'
  lightningcss>lightningcss-linux-arm64-musl: '-'
  lightningcss>lightningcss-linux-x64-musl: '-'
  lightningcss>lightningcss-win32-arm64-msvc: '-'
  lightningcss>lightningcss-win32-x64-msvc: '-'
  '@tailwindcss/oxide>@tailwindcss/oxide-android-arm64': '-'
  '@tailwindcss/oxide>@tailwindcss/oxide-darwin-arm64': '-'
  '@tailwindcss/oxide>@tailwindcss/oxide-darwin-x64': '-'
  '@tailwindcss/oxide>@tailwindcss/oxide-freebsd-x64': '-'
  '@tailwindcss/oxide>@tailwindcss/oxide-linux-arm-gnueabihf': '-'
  '@tailwindcss/oxide>@tailwindcss/oxide-linux-arm64-gnu': '-'
  '@tailwindcss/oxide>@tailwindcss/oxide-linux-arm64-musl': '-'
  '@tailwindcss/oxide>@tailwindcss/oxide-win32-arm64-msvc': '-'
  '@tailwindcss/oxide>@tailwindcss/oxide-win32-x64-msvc': '-'
  '@tailwindcss/oxide>@tailwindcss/oxide-linux-x64-musl': '-'
  rollup>@rollup/rollup-android-arm-eabi: '-'
  rollup>@rollup/rollup-android-arm64: '-'
  rollup>@rollup/rollup-darwin-arm64: '-'
  rollup>@rollup/rollup-darwin-x64: '-'
  rollup>@rollup/rollup-freebsd-arm64: '-'
  rollup>@rollup/rollup-freebsd-x64: '-'
  rollup>@rollup/rollup-linux-arm-gnueabihf: '-'
  rollup>@rollup/rollup-linux-arm-musleabihf: '-'
  rollup>@rollup/rollup-linux-arm64-gnu: '-'
  rollup>@rollup/rollup-linux-arm64-musl: '-'
  rollup>@rollup/rollup-linux-loong64-gnu: '-'
  rollup>@rollup/rollup-linux-loong64-musl: '-'
  rollup>@rollup/rollup-linux-ppc64-gnu: '-'
  rollup>@rollup/rollup-linux-ppc64-musl: '-'
  rollup>@rollup/rollup-linux-riscv64-gnu: '-'
  rollup>@rollup/rollup-linux-riscv64-musl: '-'
  rollup>@rollup/rollup-linux-s390x-gnu: '-'
  rollup>@rollup/rollup-linux-x64-musl: '-'
  rollup>@rollup/rollup-openbsd-x64: '-'
  rollup>@rollup/rollup-openharmony-arm64: '-'
  rollup>@rollup/rollup-win32-arm64-msvc: '-'
  rollup>@rollup/rollup-win32-ia32-msvc: '-'
  rollup>@rollup/rollup-win32-x64-gnu: '-'
  rollup>@rollup/rollup-win32-x64-msvc: '-'
  '@expo/ngrok-bin>@expo/ngrok-bin-darwin-arm64': '-'
  '@expo/ngrok-bin>@expo/ngrok-bin-darwin-x64': '-'
  '@expo/ngrok-bin>@expo/ngrok-bin-freebsd-ia32': '-'
  '@expo/ngrok-bin>@expo/ngrok-bin-freebsd-x64': '-'
  '@expo/ngrok-bin>@expo/ngrok-bin-linux-arm64': '-'
  '@expo/ngrok-bin>@expo/ngrok-bin-linux-arm': '-'
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
